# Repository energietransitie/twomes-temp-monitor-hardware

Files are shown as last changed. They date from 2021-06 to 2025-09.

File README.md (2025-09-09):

# Twomes Temperature Monitor Hardware

This repository contains the open hardware design files for the battery powered Twomes Temperature Monitor hardware, which can read measurement data from a varity of sensors:
* two [DS18b20(Z)](https://www.maximintegrated.com/en/products/sensors/DS18B20.html) temperature sensors in clamps that can be connected the supply water pipe (from the boiler to the hydronic radiators) and return water pipe (from the hydronic radiators to the boiler);
* an [Si7051](https://www.silabs.com/sensors/temperature/si705x/device.si7051) sensor mounted 
on the main PCB itself to measure room temperature;
* a [Twomes CO₂ Monitor Shield](https://github.com/energietransitie/twomes-co2-monitor-hardware) with the [WeMos D1 Mini shield](https://www.wemos.cc/en/latest/d1_mini_shield/index.html) form factor that measures temperature via an [Si7051](https://www.silabs.com/sensors/temperature/si705x/device.si7051) sensor and a Sensirion [SCD41](https://www.sensirion.com/en/environmental-sensors/carbon-dioxide-sensors/carbon-dioxide-sensor-scd4x/) sensor that measures CO₂ concentration, relative humidity and temperatue;
* a [SEK-SCD41](https://www.sensirion.com/en/environmental-sensors/evaluation-kit-sek-environmental-sensing/evaluation-kit-sek-scd41/) evaluation board that that measures CO₂ concentration, relative humidity and temperature.

The Twomes Temperature Monitor hardware can wirelessly send data to the [Twomes P1 Gateway measurement device](https://github.com/energietransitie/twomes-p1-gateway-firmware) using [ESP-NOW](https://www.espressif.com/en/products/software/esp-now/overview).

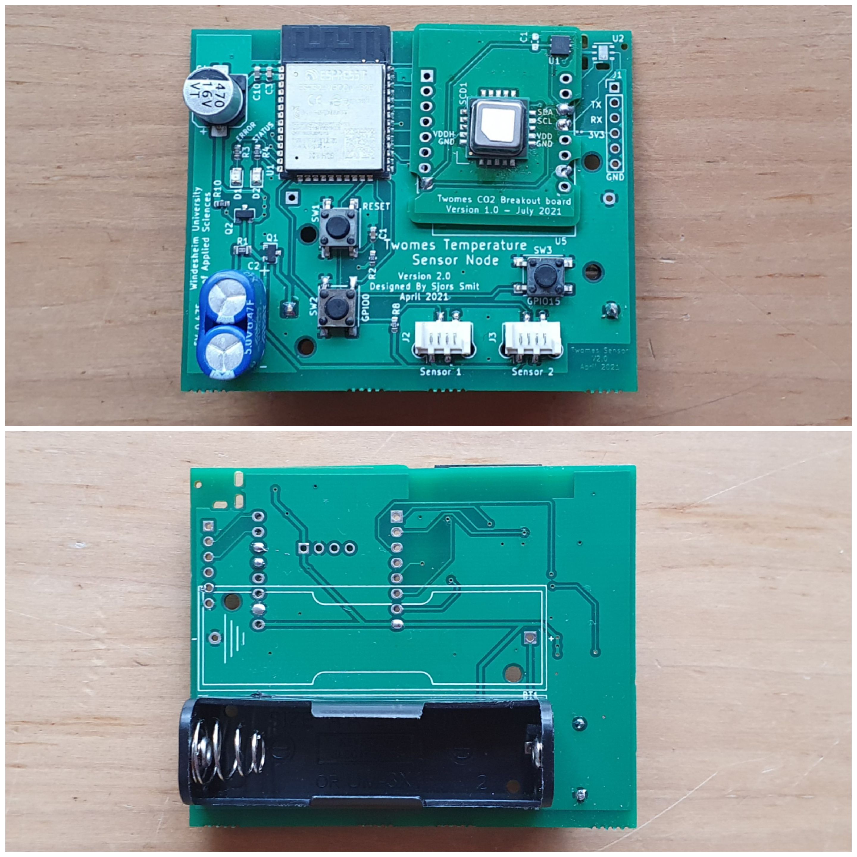
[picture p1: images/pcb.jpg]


## Table of contents
* [General info](#general-info)
* [Producing](#producing)
* [Developing](#developing) 
* [Features](#features)
* [Status](#status)
* [License](#license)
* [Citation](#citation)
* [Credits](#credits)

## General info
This repository contains the the source files and fabrication files of the hardware designs of theTwomes Room Monitor and Twomes Boiler Monitor pcb and its enclosure. It also includes a `docs` folder with recent printouts of the [schematics](./docs/twomes-temp-monitor-hardware-sch.pdf) and [PCB layout](./docs/twomes-temp-monitor-hardware-pcb.pdf). 

For the associated firmwware that you can run on this hardware, please see the following repositories:
* [twomes-twomes-room-monitor-firmware](https://github.com/energietransitie/twomes-room-monitor-firmware);
* [twomes-twomes-boiler-monitor-firmware](https://github.com/energietransitie/twomes-boiler-monitor-firmware);

## Producing
### Printed Circuit Board
To fabricate the printed circuit board you can use various PCB services. 

The folder [pcb/jlcpcb](./pcb/jlcpcb) includes all exported files needed to have the PCBs manufactured by [JLCPCB](https://www.jlcpcb.com). 
Upload the [zipped gerber files](./pcb\jlcpcb\gerber\gerber-TwomesSensor.zip) to the [JLCPCB quote page](https://cart.jlcpcb.com/quote), select the amount of PCBs and a colour for the silkscreen. All other options can be left on default. If SMT assembly is desired, also select this option before ordering. This will take you to a page where the BOM and POS file can be uploaded.  

Assembly of components depends on the variant you need:
* for assembly of a Twomes Boiler Monitor PCB, use the files [BOM-TwomesBoilerSensor.csv](./pcb/jlcpcb/assembly/boiler-monitor/BOM-TwomesBoilerSensor.csv) and [CPL-TwomesBoilerSensor.csv](./pcb/jlcpcb/assembly/boiler-monitor/CPL-TwomesBoilerSensor.csv);
* for assembly of a Twomes Room Monitor PCB, use the files [BOM-TwomesRoomSensor.csv](./pcb/jlcpcb/assembly/room-monitor/BOM-TwomesRoomSensor.csv) and [CPL-TwomesRoomSensor.csv](./pcb/jlcpcb/assembly/room-monitor/CPL-TwomesRoomSensor.csv)

N.B. All components marked "DO NOT PLACE" in the BOM-*.csv files can not be ordered from JLCPCB and need to be ordered from other services and placed manually.

### Enclosure
To fabricate the boiler monitor enclosure or the room room monitor enclosure you can use your own 3D printer or use a 3D printing service. 

Below you find a photo of the boiler enclosure. 
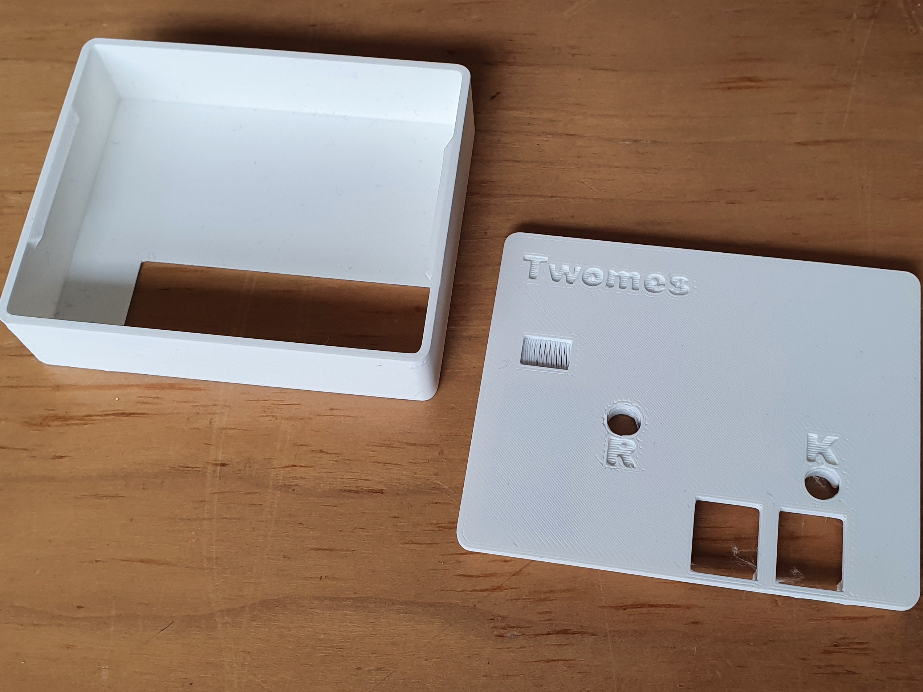
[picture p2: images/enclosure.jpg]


The folder [enclosure/fabrication](./enclosure/fabrication) contains exported STL files. You can print two types of enclusure:
* all enclusures share the same [case](./enclosure/fabrication/twomes-temp-monitor-enclosure-case.stl) and one [button](./enclosure/fabrication/twomes-temp-monitor-enclosure-button.stl)
* for a Twomes Boiler Monitor you need a [boiler monitor lid](./enclosure/fabrication/twomes-boiler-monitor-enclosure-lid.stl) and two [sensor clamps](./enclosure/fabrication/twomes-boiler-monitor-enclosure-clamp.stl); 
* for a Twomes Room Monitor you need a [room monitor lid](./enclosure/fabrication/twomes-room-monitor-enclosure-lid.stl).

The STL files can be imported into any slicer and turned into G-Code for a 3D printer. You can also upload the STL files to an online 3D printing service of your choice.

## Developing

### Printed Circuit Board
To change the hardware design of the PCB, you need:
* [KiCad](https://www.kicad.org/download/) installed to change te PCB design. 

The KiCad source files of the PCB can be found in the folder [pcb](./pcb).

To convert the PCBs into a format suitable for fabrication, consult the webpage of your PCB manufacturer of choice. For example, see the [JLCPCB guide on how to export Gerbers](https://support.jlcpcb.com/article/149-how-to-generate-gerber-and-drill-files-in-kicad) and the  [JLCPCB guide how to export the BOM and POS files](https://support.jlcpcb.com/article/84-how-to-generate-the-bom-and-centroid-file-from-kicad). You may also use a KiCad plug-in for this purpose such as [kicad-jlcpcb-tools](https://github.com/Bouni/kicad-jlcpcb-tools).

### Enclosure
To change the hardware design of the enclosure, you need either:
* [Autodesk Fusion 360](https://www.kicad.org/download/) installed (Autodesk provides 30 day free trials and [free one-year educational access](https://www.autodesk.com/education/edu-software/overview?sorting=featured&filters=individual) to its products and services for eligible students, teachers and research staff); 
* or [FreeCAD](https://www.freecadweb.org/), an open source alternative.

The source files of the enclosure can be found in the folder [enclosure](./enclosure). We include both .f3d source files and .step source files we obtained after conversion.
## Features
The Twomes Temperature Monitor device features the follwoing main hardware components:
* [ESP32-WROOM-32E](https://www.espressif.com/sites/default/files/documentation/esp32-wroom-32e_esp32-wroom-32ue_datasheet_en.pdf) module;
* supercapacitor to assist the battery in high-current bursts.
* battery holder for a 3.6 V AA-size battery, such as the SAFT LS14500 Lithium Thionyl battery.
* FTDI compatible serial programming header (3.3 V).

To-do:
* remove `SW2` (not used in newer firmware)
* remove holes above SW2 and SW3 in enclosure lids (SW3 not used in newer firmware; SW2 does not need to be user accessible, only used during deployment))  
* remove letters 'R' and 'K' from enclusure lids (only a single end-user accessible button used in newer firmware )
## Status
Project is: _in progress_

## License
The hardware designs in this repository are available under the [CERN-OHL-P v2 license](./LICENSE), Copyright 2022 [Research group Energy Transition, Windesheim University of Applied Sciences](https://windesheim.nl/energietransitie)

## Citation

If you use this repository in your research or work, please cite the following pre-print, which describes the overall NeedForHeat DataGear system of which this repository is a part:

> Ter Hofte, H., & van Ravenzwaaij, N. (2025). *NeedForHeat DataGear: An Open Monitoring System to Accelerate the Residential Heating Transition*. arXiv preprint arXiv:2509.06927. https://doi.org/10.48550/arXiv.2509.06927

**Note:** This is a pre-print submitted on 8 Sep 2025 and has not yet been peer-reviewed. For the full paper, see [https://arxiv.org/abs/2509.06927](https://arxiv.org/abs/2509.06927).

## Credits
This open hardware design is made by:
* Sjors Smit · [@Shorts1999](https://github.com/Shorts1999)

Thanks also go to:
* Fredrik-Otto Lautenbag ·  [@Fredrik1997](https://github.com/Fredrik1997)
* Gerwin Buma ·  [@GerwinBuma](https://github.com/GerwinBuma) 
* Marco Winkelman · [@MarcoW71](https://github.com/MarcoW71)

Product owner:
* Marco Winkelman · [@MarcoW71](https://github.com/MarcoW71)

We use and gratefully acknowlegde the efforts of the makers of the following designs:
* [KiCad Libraries](https://kicad.github.io/), by the KiCad Development Team, licensed under [an adapted version of the CC-BY-SA 4.0 License](https://www.kicad.org/libraries/license/)

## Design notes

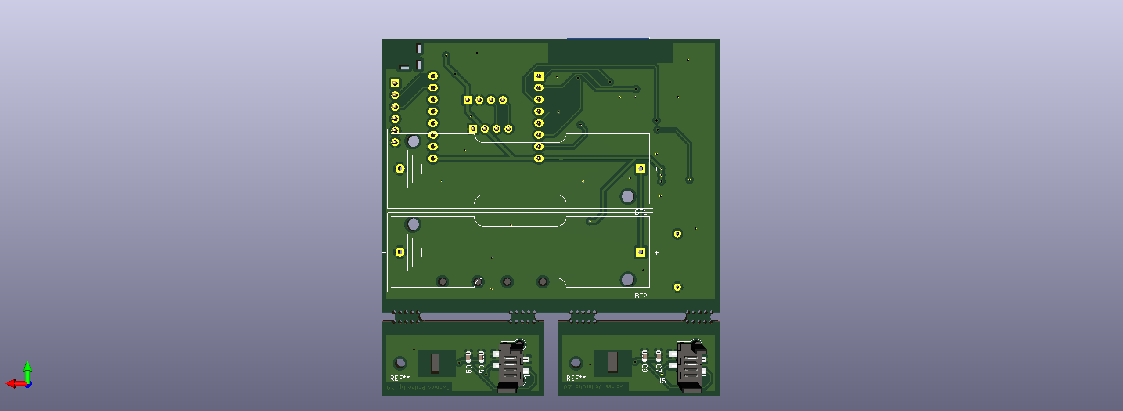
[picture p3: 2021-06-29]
images/twomes-temp-monitor-hardware-bottom.png

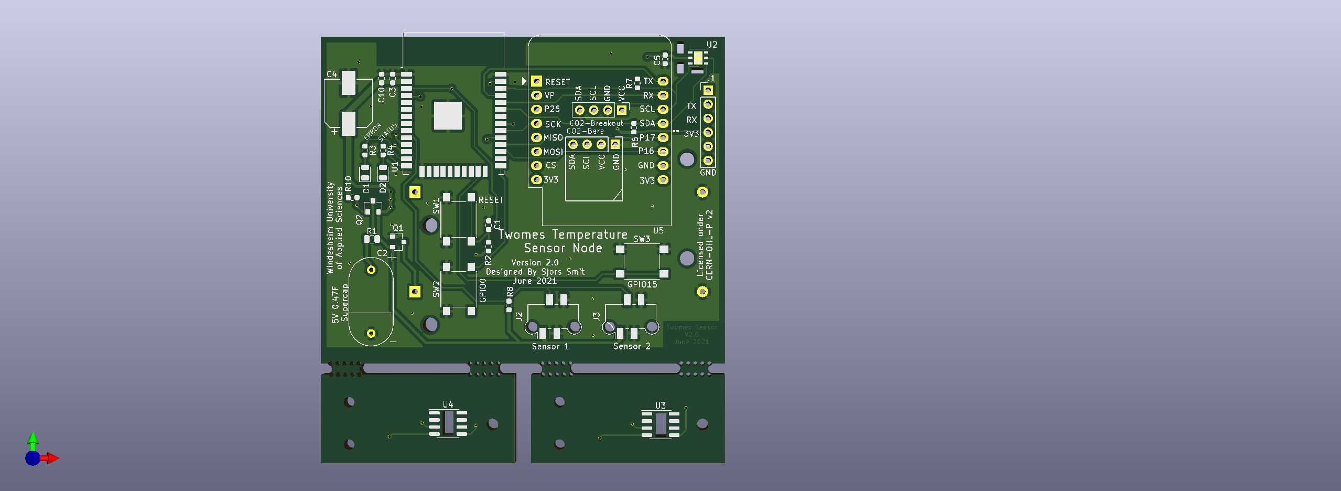
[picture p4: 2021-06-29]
images/twomes-temp-monitor-hardware-top-nomodels.png

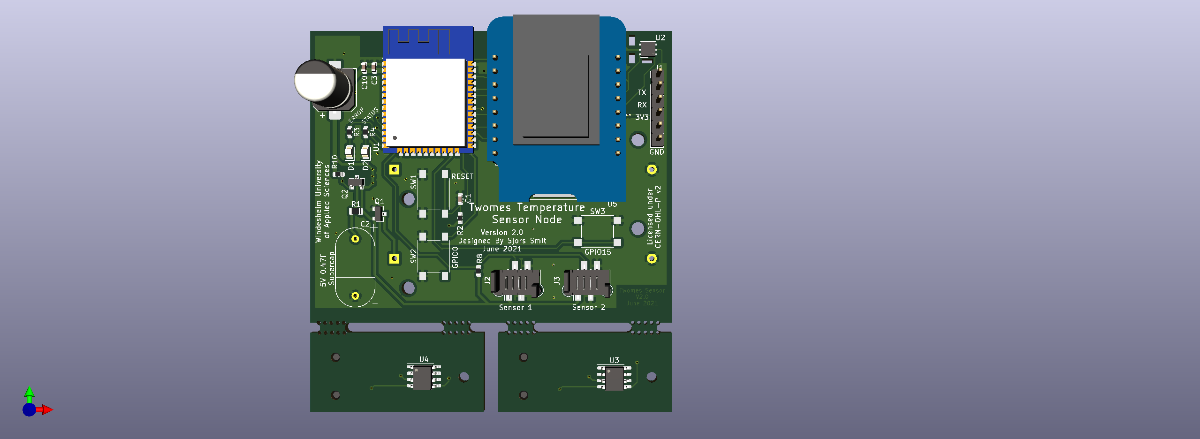
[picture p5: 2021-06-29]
images/twomes-temp-monitor-hardware-top.png

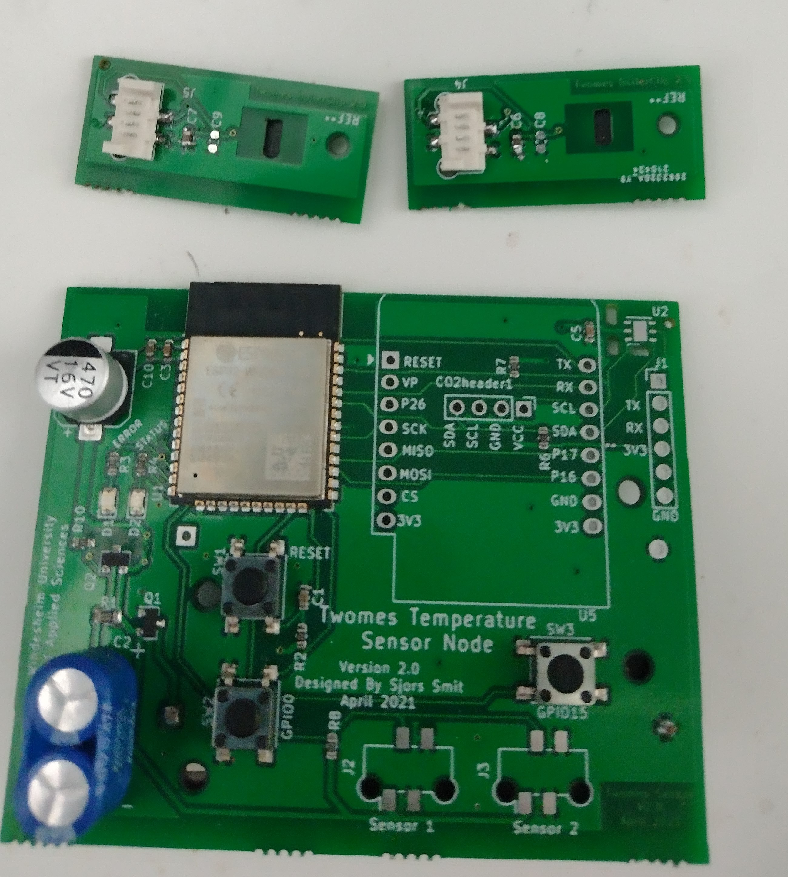
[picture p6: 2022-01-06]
images/Front.jpg

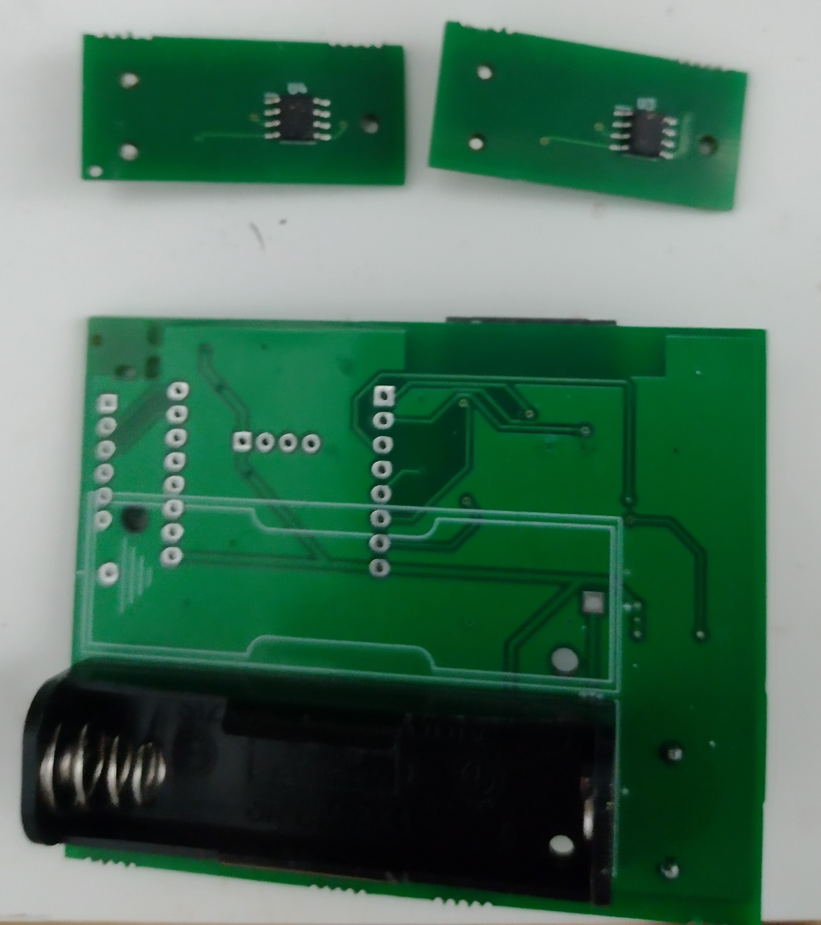
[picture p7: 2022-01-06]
images/Back.jpg

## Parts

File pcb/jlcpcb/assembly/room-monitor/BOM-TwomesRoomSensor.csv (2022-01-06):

Comment | Designator | Footprint | LCSC
LS14500 | BT1,BT2 | Battery:BatteryHolder_Keystone_2460_1xAA | DO NOT PLACE
1uF | C1,C6,C7 | Capacitor_SMD:C_0603_1608Metric | C15849
0.47F | C2 | SuperCap | DO NOT PLACE
470uF | C4 | Capacitor_SMD:CP_Elec_8x10.5 | C141429
100nF | C3,C5,C8,C9 | Capacitor_SMD:C_0603_1608Metric | C14663
10uF | C10 | Capacitor_SMD:C_0603_1608Metric | C19702
RED_LED | D1 | LED_SMD:LED_0805_2012Metric | C84256
GREEN_LED | D2 | LED_SMD:LED_0805_2012Metric | C2297
Female header | J1 | Connector_PinHeader_2.54mm:PinHeader_1x06_P2.54mm_Vertical | DO NOT PLACE
Molex PicoFlex 90814 | J2,J3,J4,J5 | Connector_Molex:Molex_Picoflex_90814-0004_2x02_P1.27mm_Vertical | DO NOT PLACE
SolderJumper | JP1 | Resistor_SMD:R_0201_0603Metric | DO NOT PLACE
PMV48XP,215 | Q1,Q2 | Package_TO_SOT_SMD:SOT-23 | C75560
100R | R1 | Resistor_SMD:R_0805_1608Metric | C17408
10K | R2 | Resistor_SMD:R_0603_1608Metric | C25804
1K | R3,R4 | Resistor_SMD:R_0603_1608Metric | C21190
10k | R6,R7,R10 | Resistor_SMD:R_0603_1608Metric | C25804
4k7 | R8 | Resistor_SMD:R_0603_1608Metric | C23162
SW_Push | SW1,SW2,SW3 | Button_Switch_SMD:SW_Push_1P1T_NO_6x6mm_H9.5mm | C83206
ESP32-WROOM-32E | U1 | RF_Module:ESP32-WROOM-32 | C701343
Si7051-A20 | U2 | Package_DFN_QFN:DFN-6-1EP_3x3mm_P0.95mm_EP1.7x2.6mm | C129804
DS18B20Z | U3,U4 | Package_SO:SOIC-8_3.9x4.9mm_P1.27mm | DO NOT PLACE
WeMos_D1_mini_breakout | U5 | Module:WEMOS_D1_mini_light_shield-Breakout | DO NOT PLACE

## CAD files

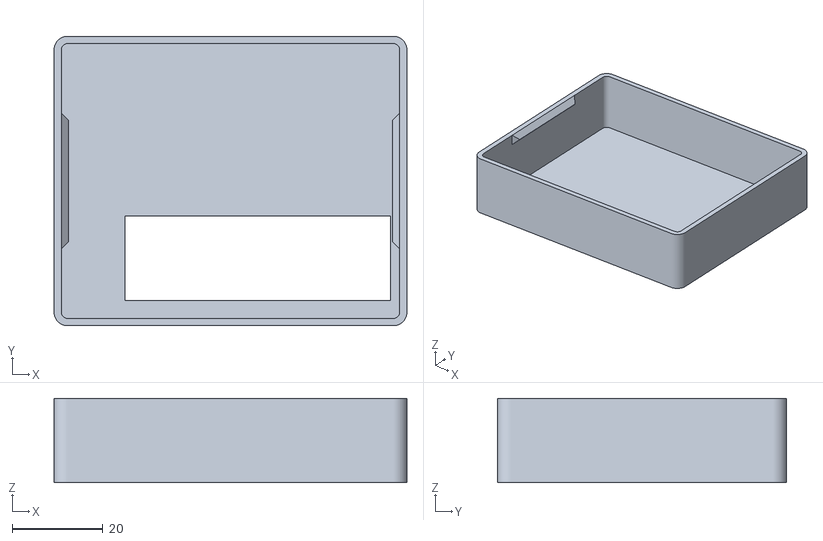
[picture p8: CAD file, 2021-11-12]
enclosure/fabrication/twomes-temp-monitor-enclosure-case.stl
77.7 x 63.7 x 18.5

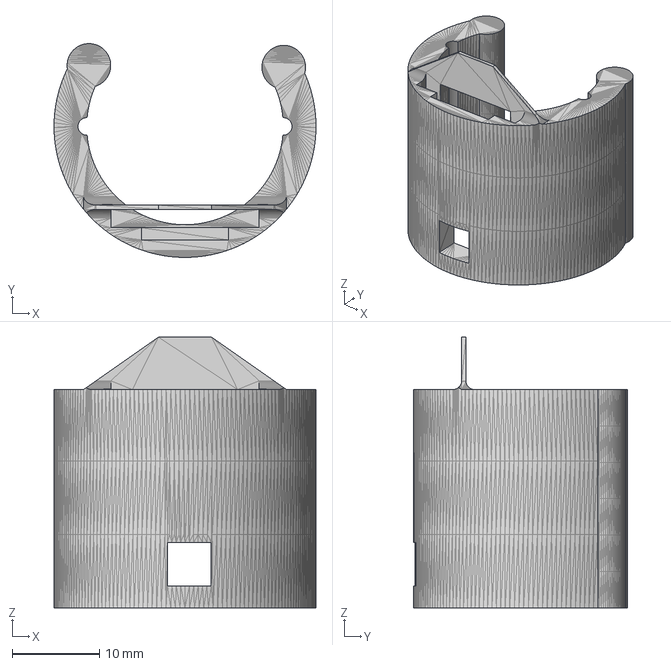
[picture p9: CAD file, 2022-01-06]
enclosure/twomes-boiler-monitor-enclosure-clamp.step
30.0 x 24.5 x 31.0 mm

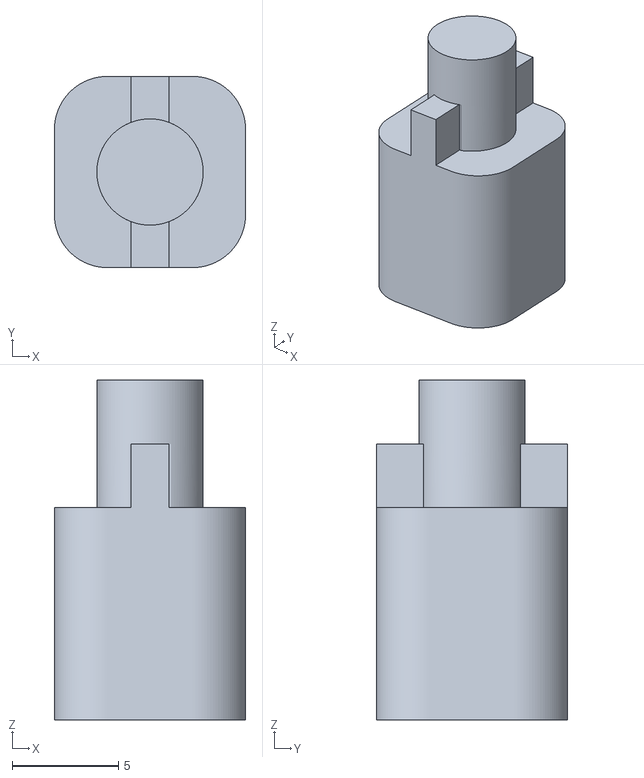
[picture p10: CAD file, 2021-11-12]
enclosure/fabrication/twomes-temp-monitor-enclosure-button.stl
9.00 x 9.00 x 16.0

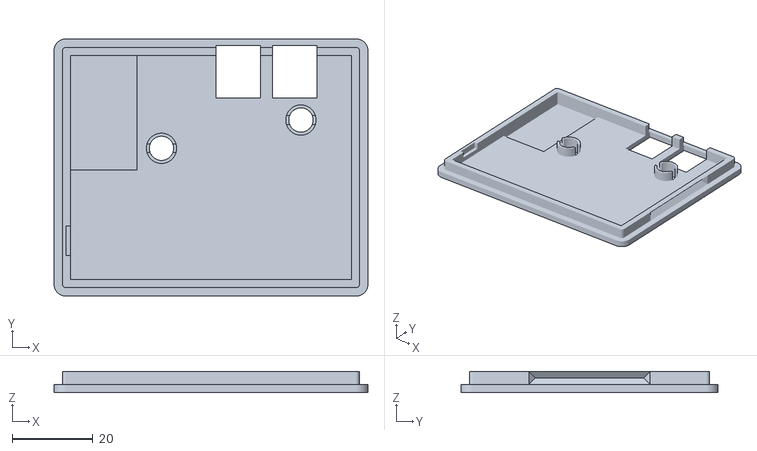
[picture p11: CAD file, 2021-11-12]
enclosure/fabrication/twomes-boiler-monitor-enclosure-lid.stl
77.7 x 63.7 x 5.20

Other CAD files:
enclosure/twomes-temp-monitor-enclosure-case.step
enclosure/twomes-room-monitor-enclosure-lid.step
enclosure/fabrication/twomes-room-monitor-enclosure-lid.stl
enclosure/twomes-temp-monitor-enclosure-button.step
enclosure/fabrication/twomes-boiler-monitor-enclosure-clamp.stl
enclosure/twomes-boiler-monitor-enclosure-clamp.f3d
enclosure/twomes-room-monitor-enclosure.f3d
enclosure/twomes-temp-monitor-enclosure-button.f3d

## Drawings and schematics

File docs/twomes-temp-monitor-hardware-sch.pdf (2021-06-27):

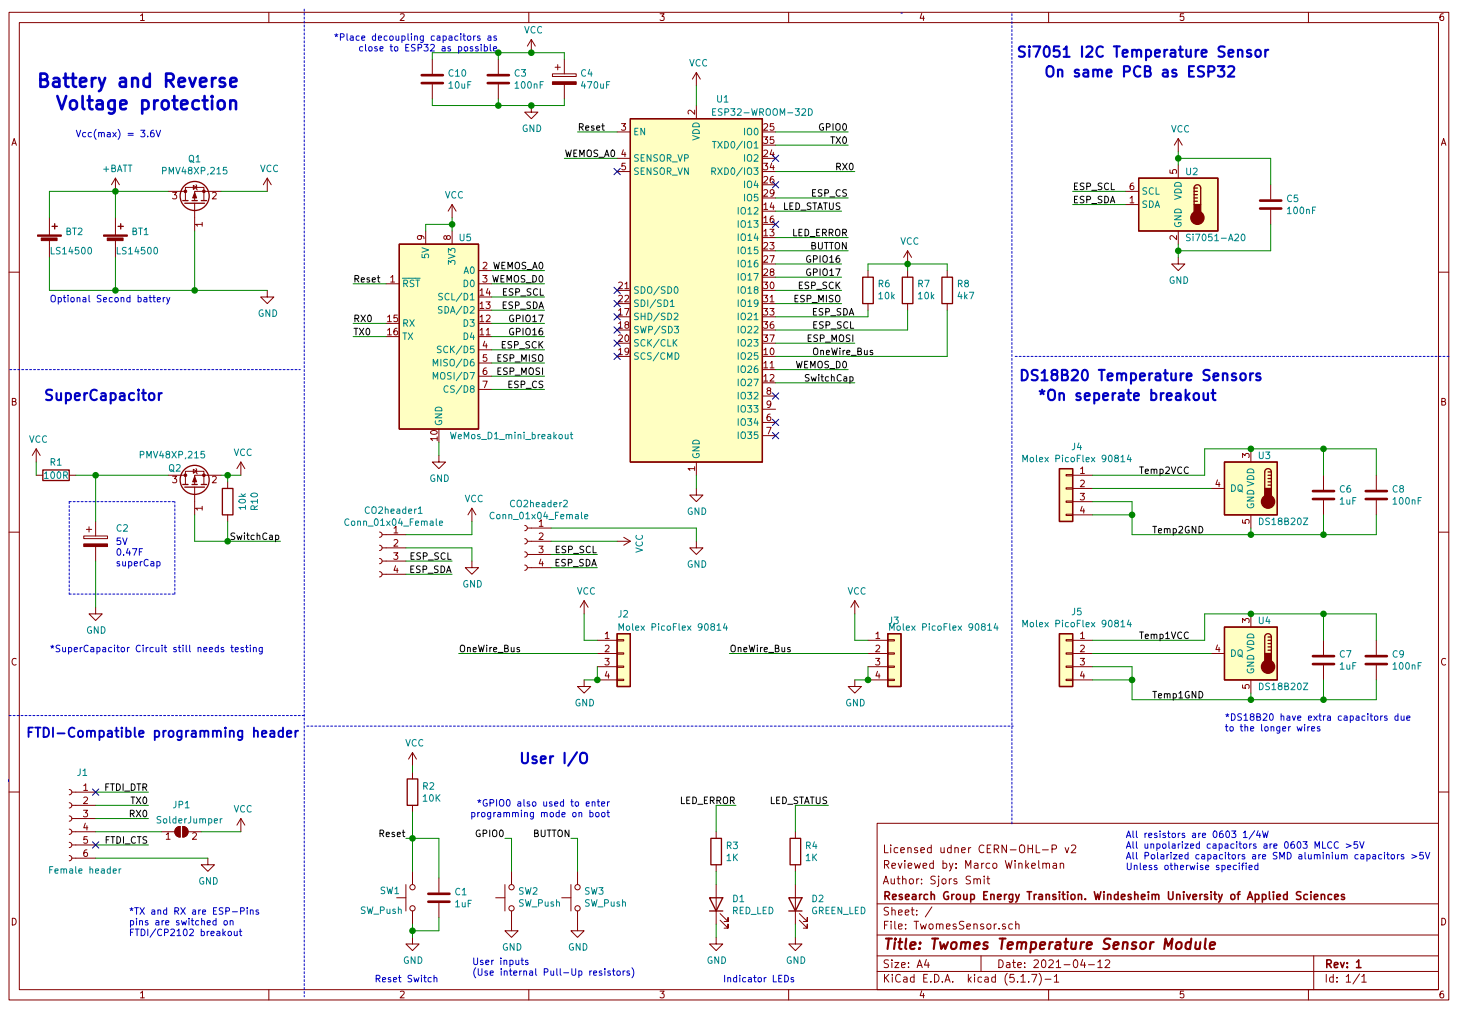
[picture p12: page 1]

*Place decoupling capacitors as
close to ESP32 as possible

Si7051 I2C Temperature Sensor
On same PCB as ESP32

2 SCK/CLK 20 SDO/SD0 21 SDI/SD1 22

*SuperCapacitor Circuit still needs testing

*DS18B20 have extra capacitors due

FTDI-Compatible programming header

to the longer wires All resistors are 0603 1/4W

*GPIO0 also used to enter programming mode on boot

Licensed udner CERN-OHL-P v2
Reviewed by: Marco Winkelman
Author: Sjors Smit
File: TwomesSensor.sch Sheet: / Research Group Energy Transition. Windesheim University of Applied Sciences

All unpolarized capacitors are 0603 MLCC >5V
All Polarized capacitors are SMD aluminium capacitors >5V
Unless otherwise specified

*TX and RX are ESP-Pins pins are switched on FTDI/CP2102 breakout

Id: 1/1 Title: Twomes Temperature Sensor Module

User inputs
(Use internal Pull-Up resistors)

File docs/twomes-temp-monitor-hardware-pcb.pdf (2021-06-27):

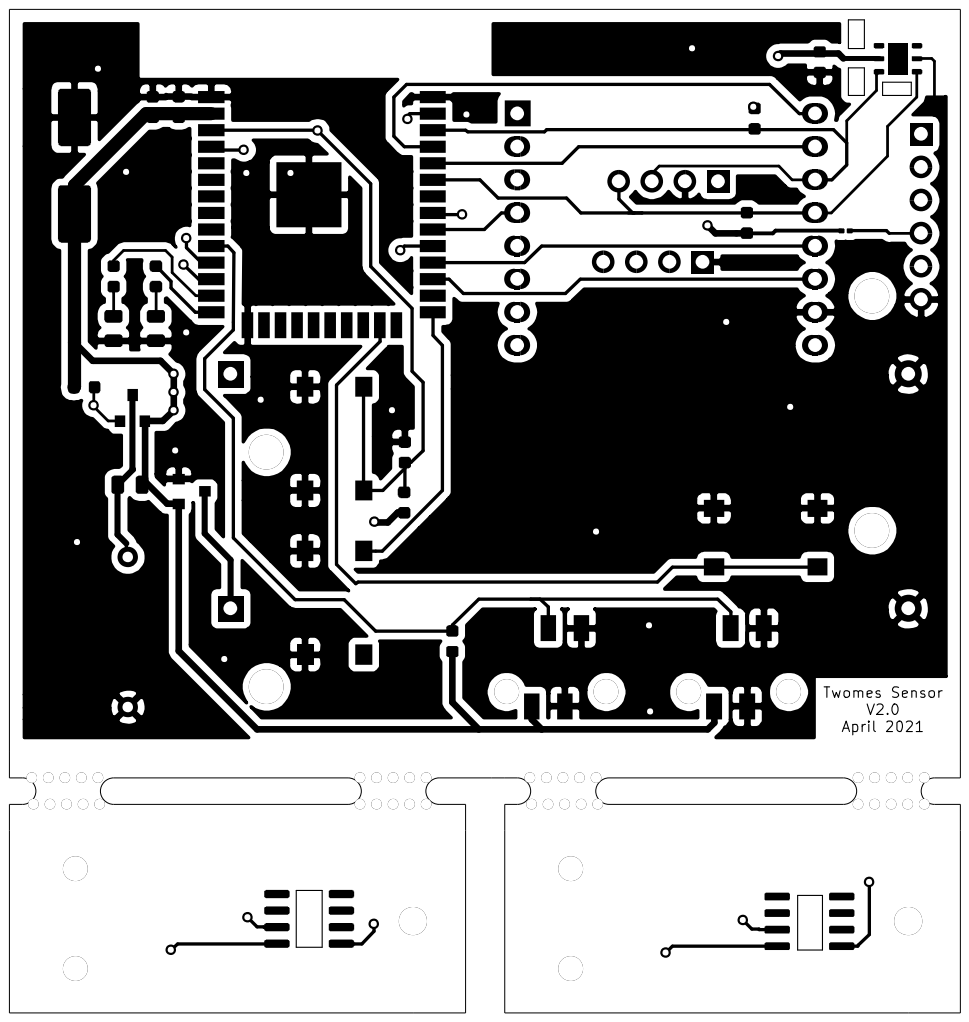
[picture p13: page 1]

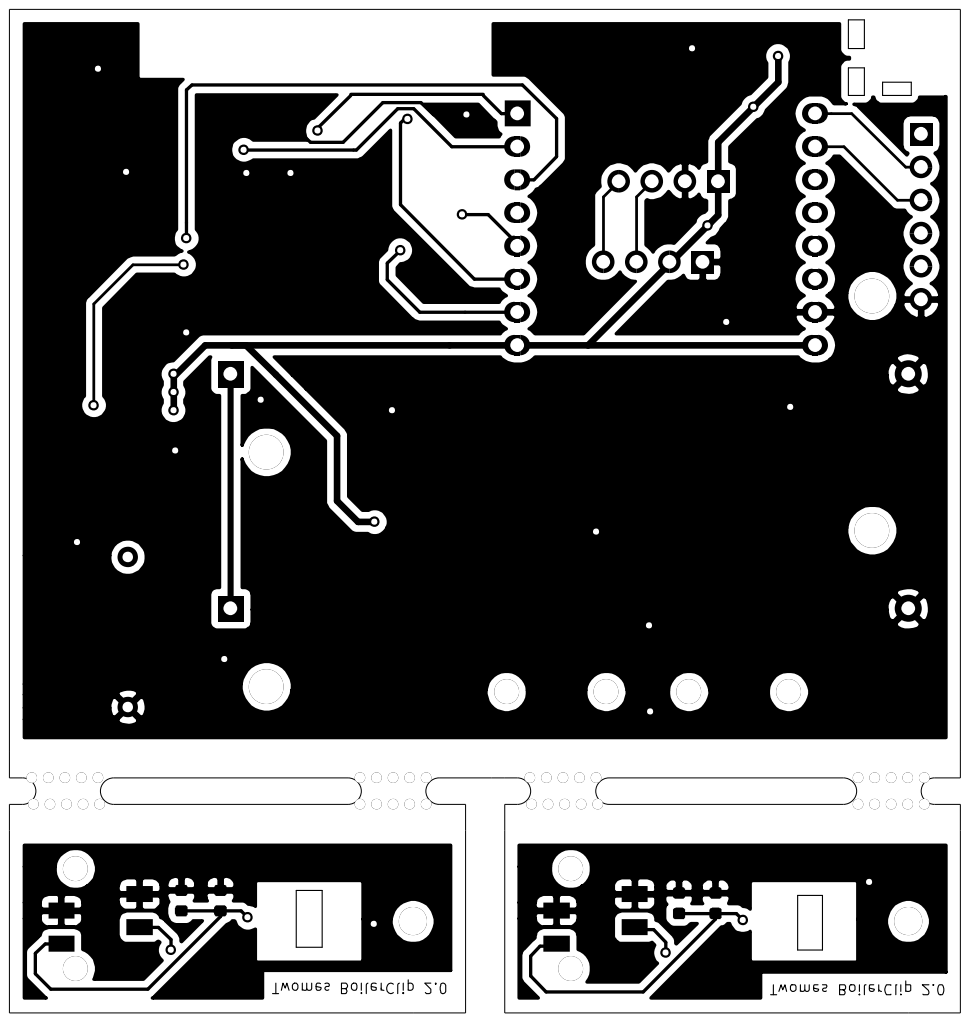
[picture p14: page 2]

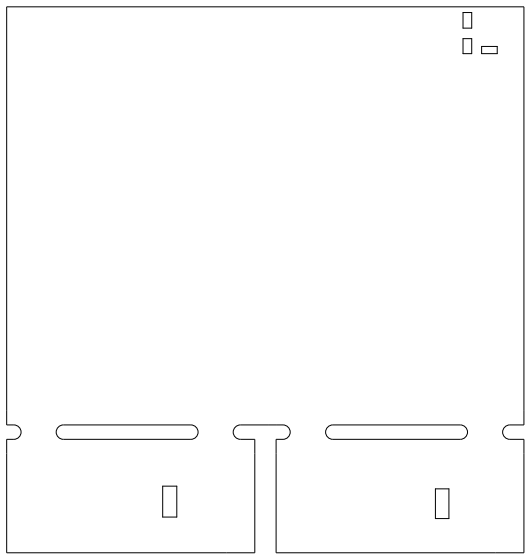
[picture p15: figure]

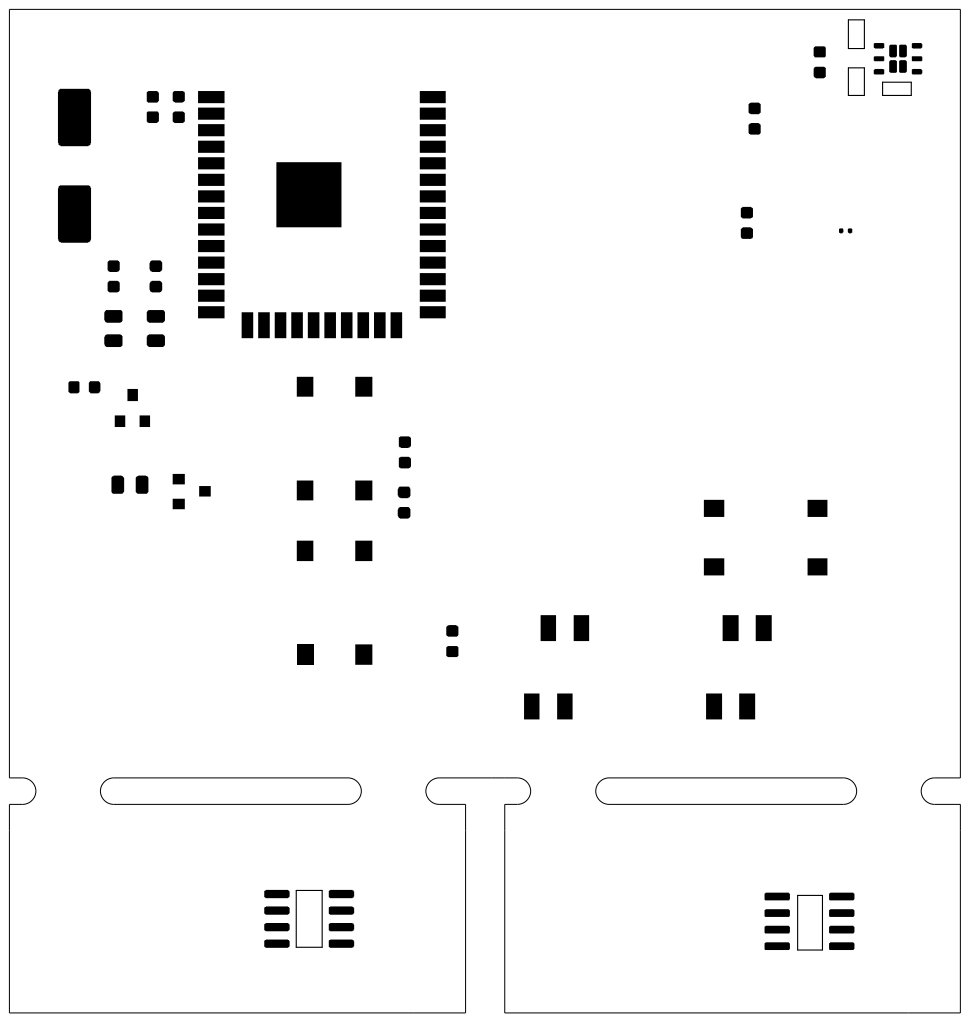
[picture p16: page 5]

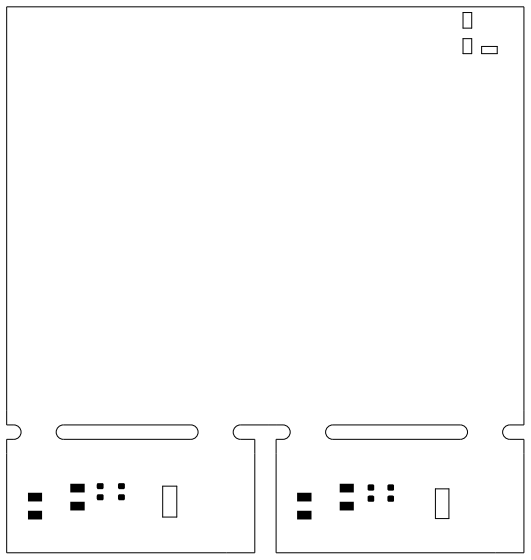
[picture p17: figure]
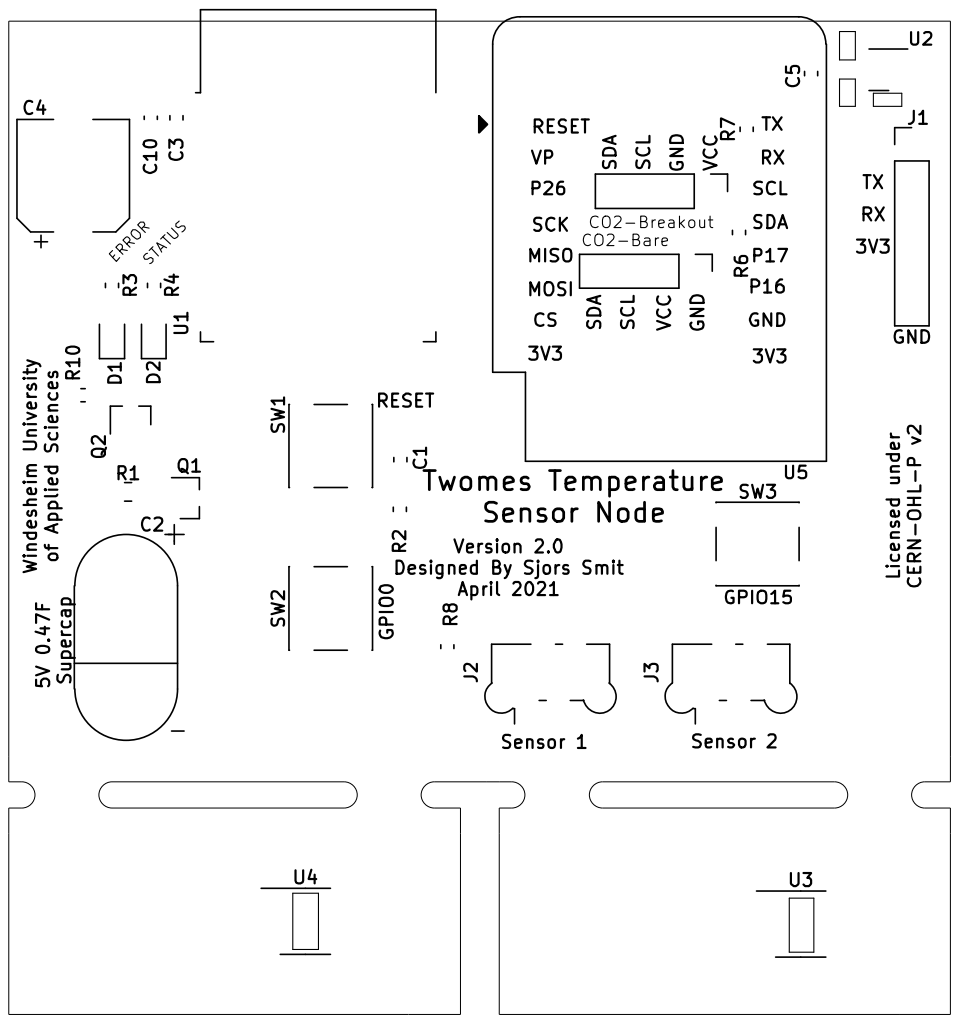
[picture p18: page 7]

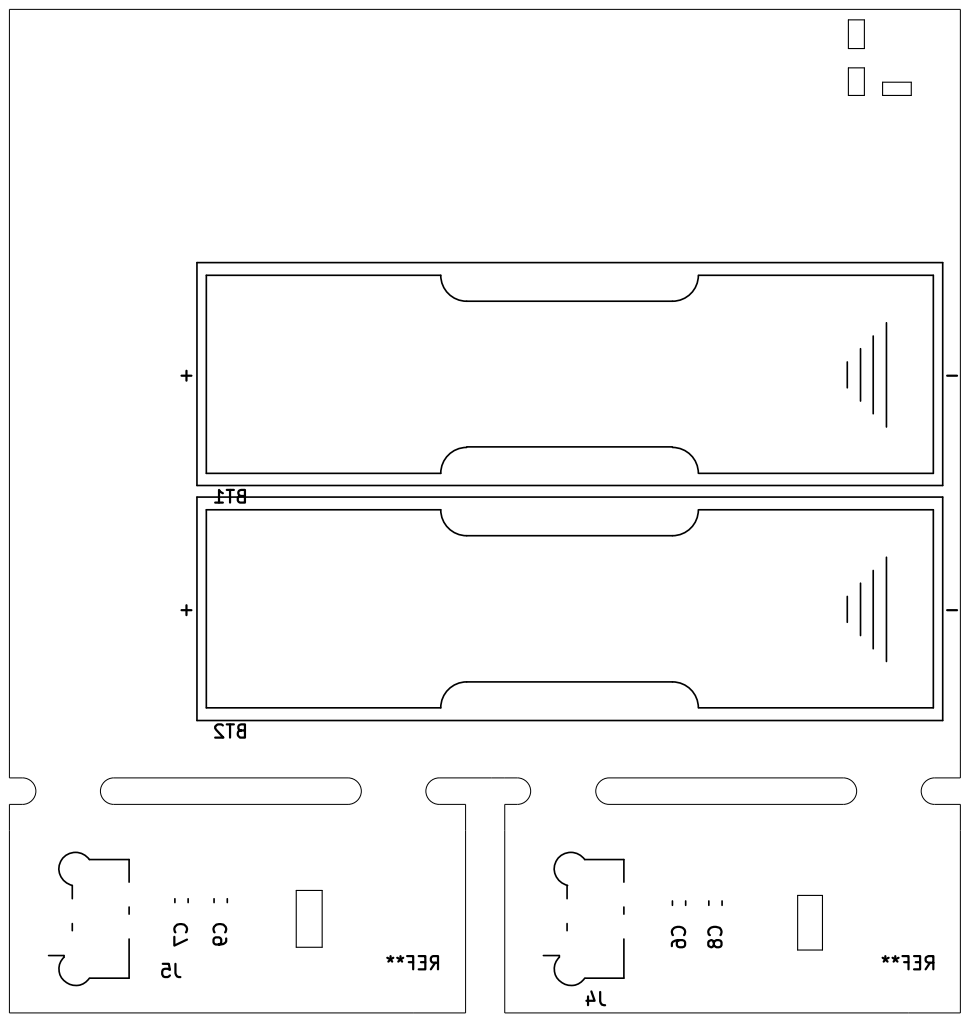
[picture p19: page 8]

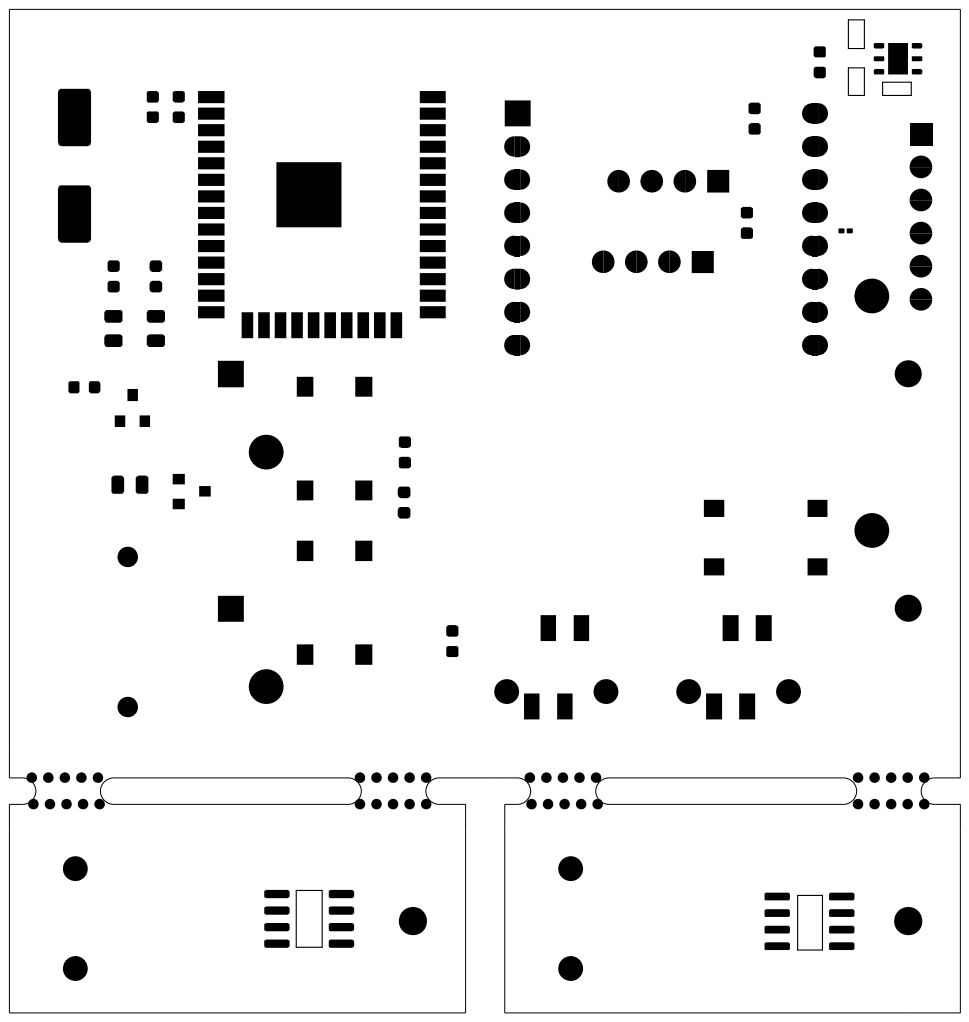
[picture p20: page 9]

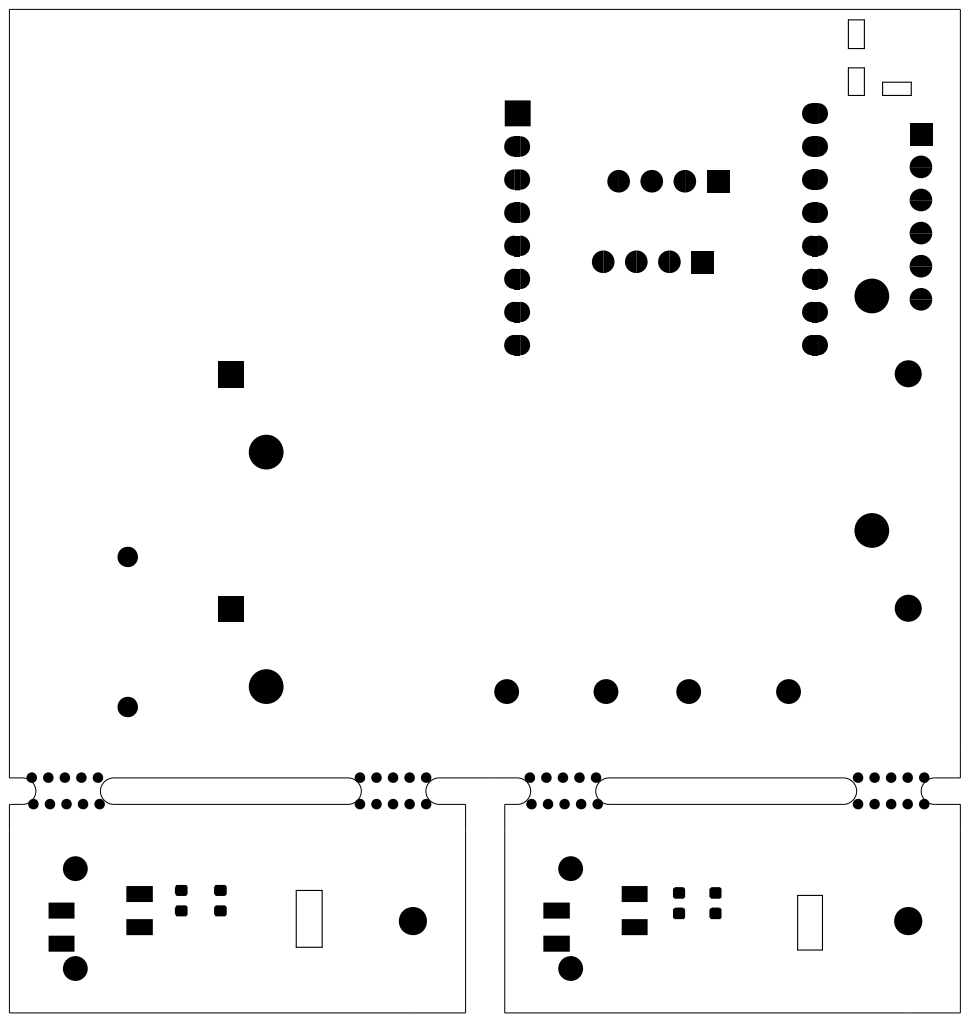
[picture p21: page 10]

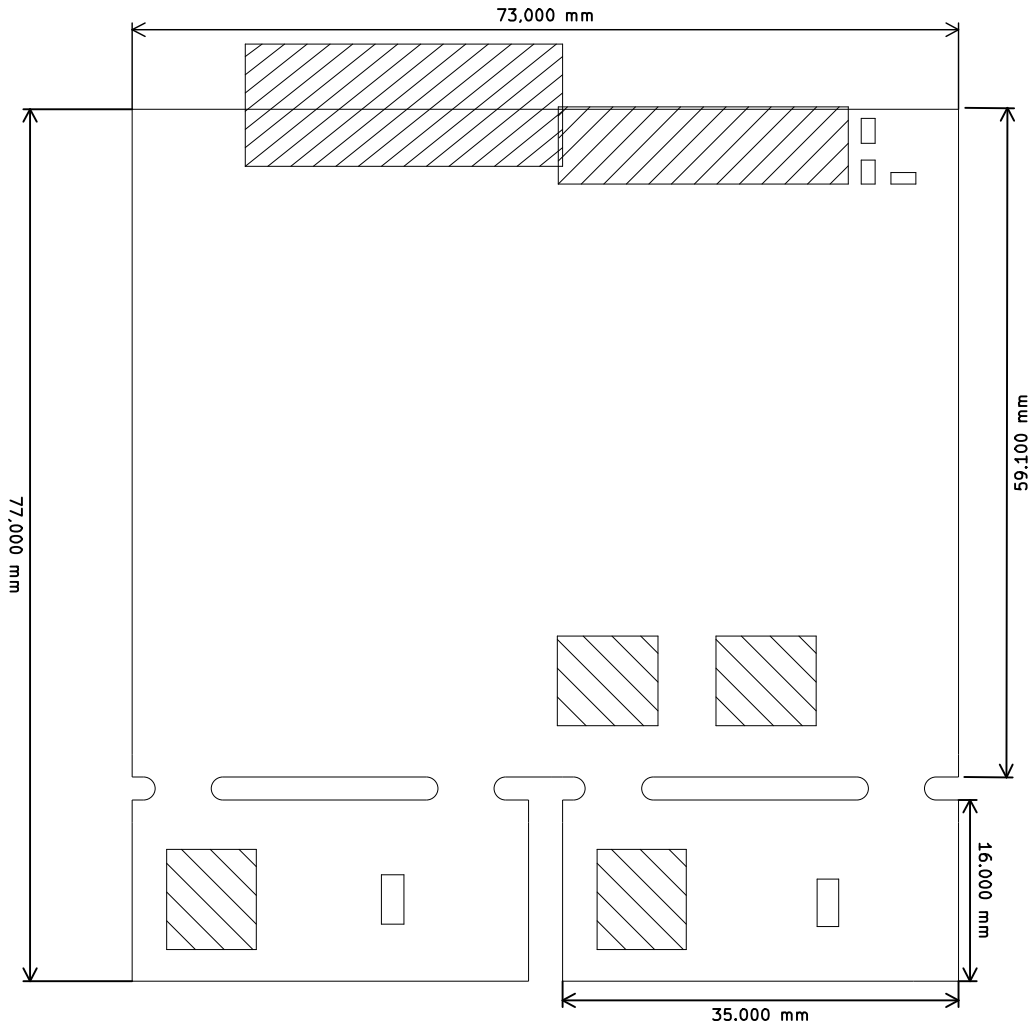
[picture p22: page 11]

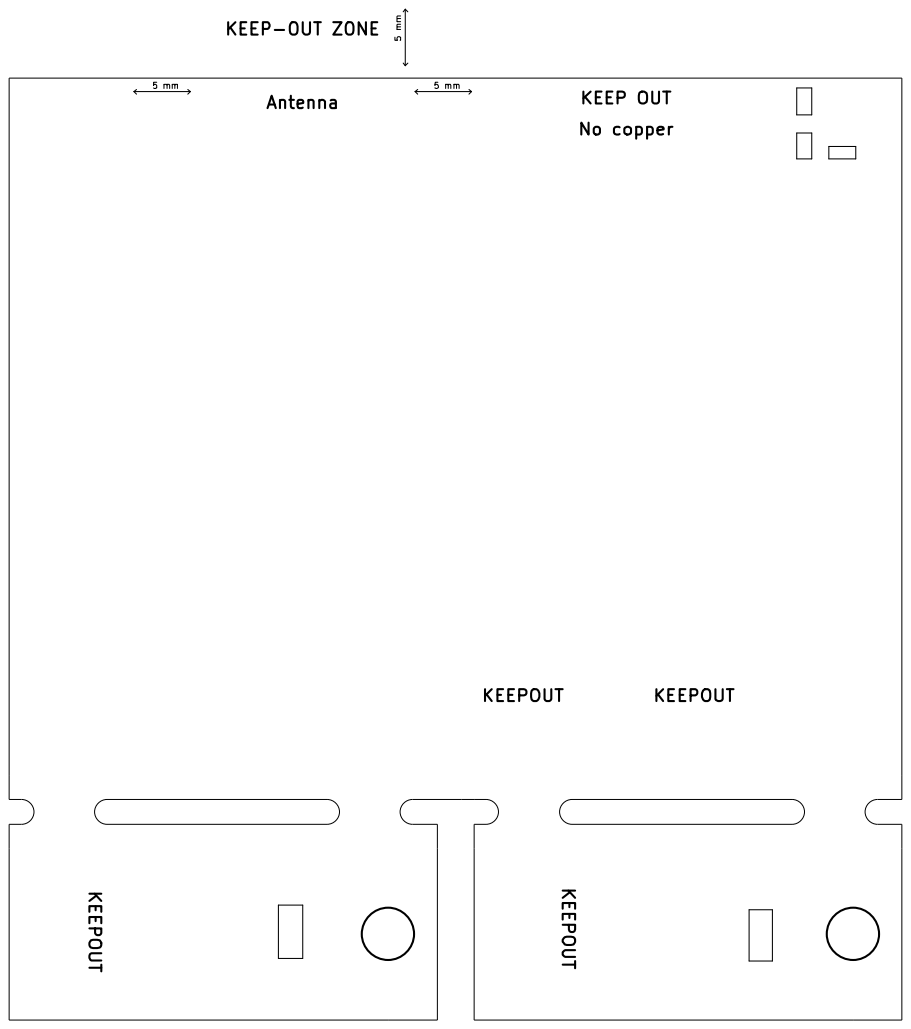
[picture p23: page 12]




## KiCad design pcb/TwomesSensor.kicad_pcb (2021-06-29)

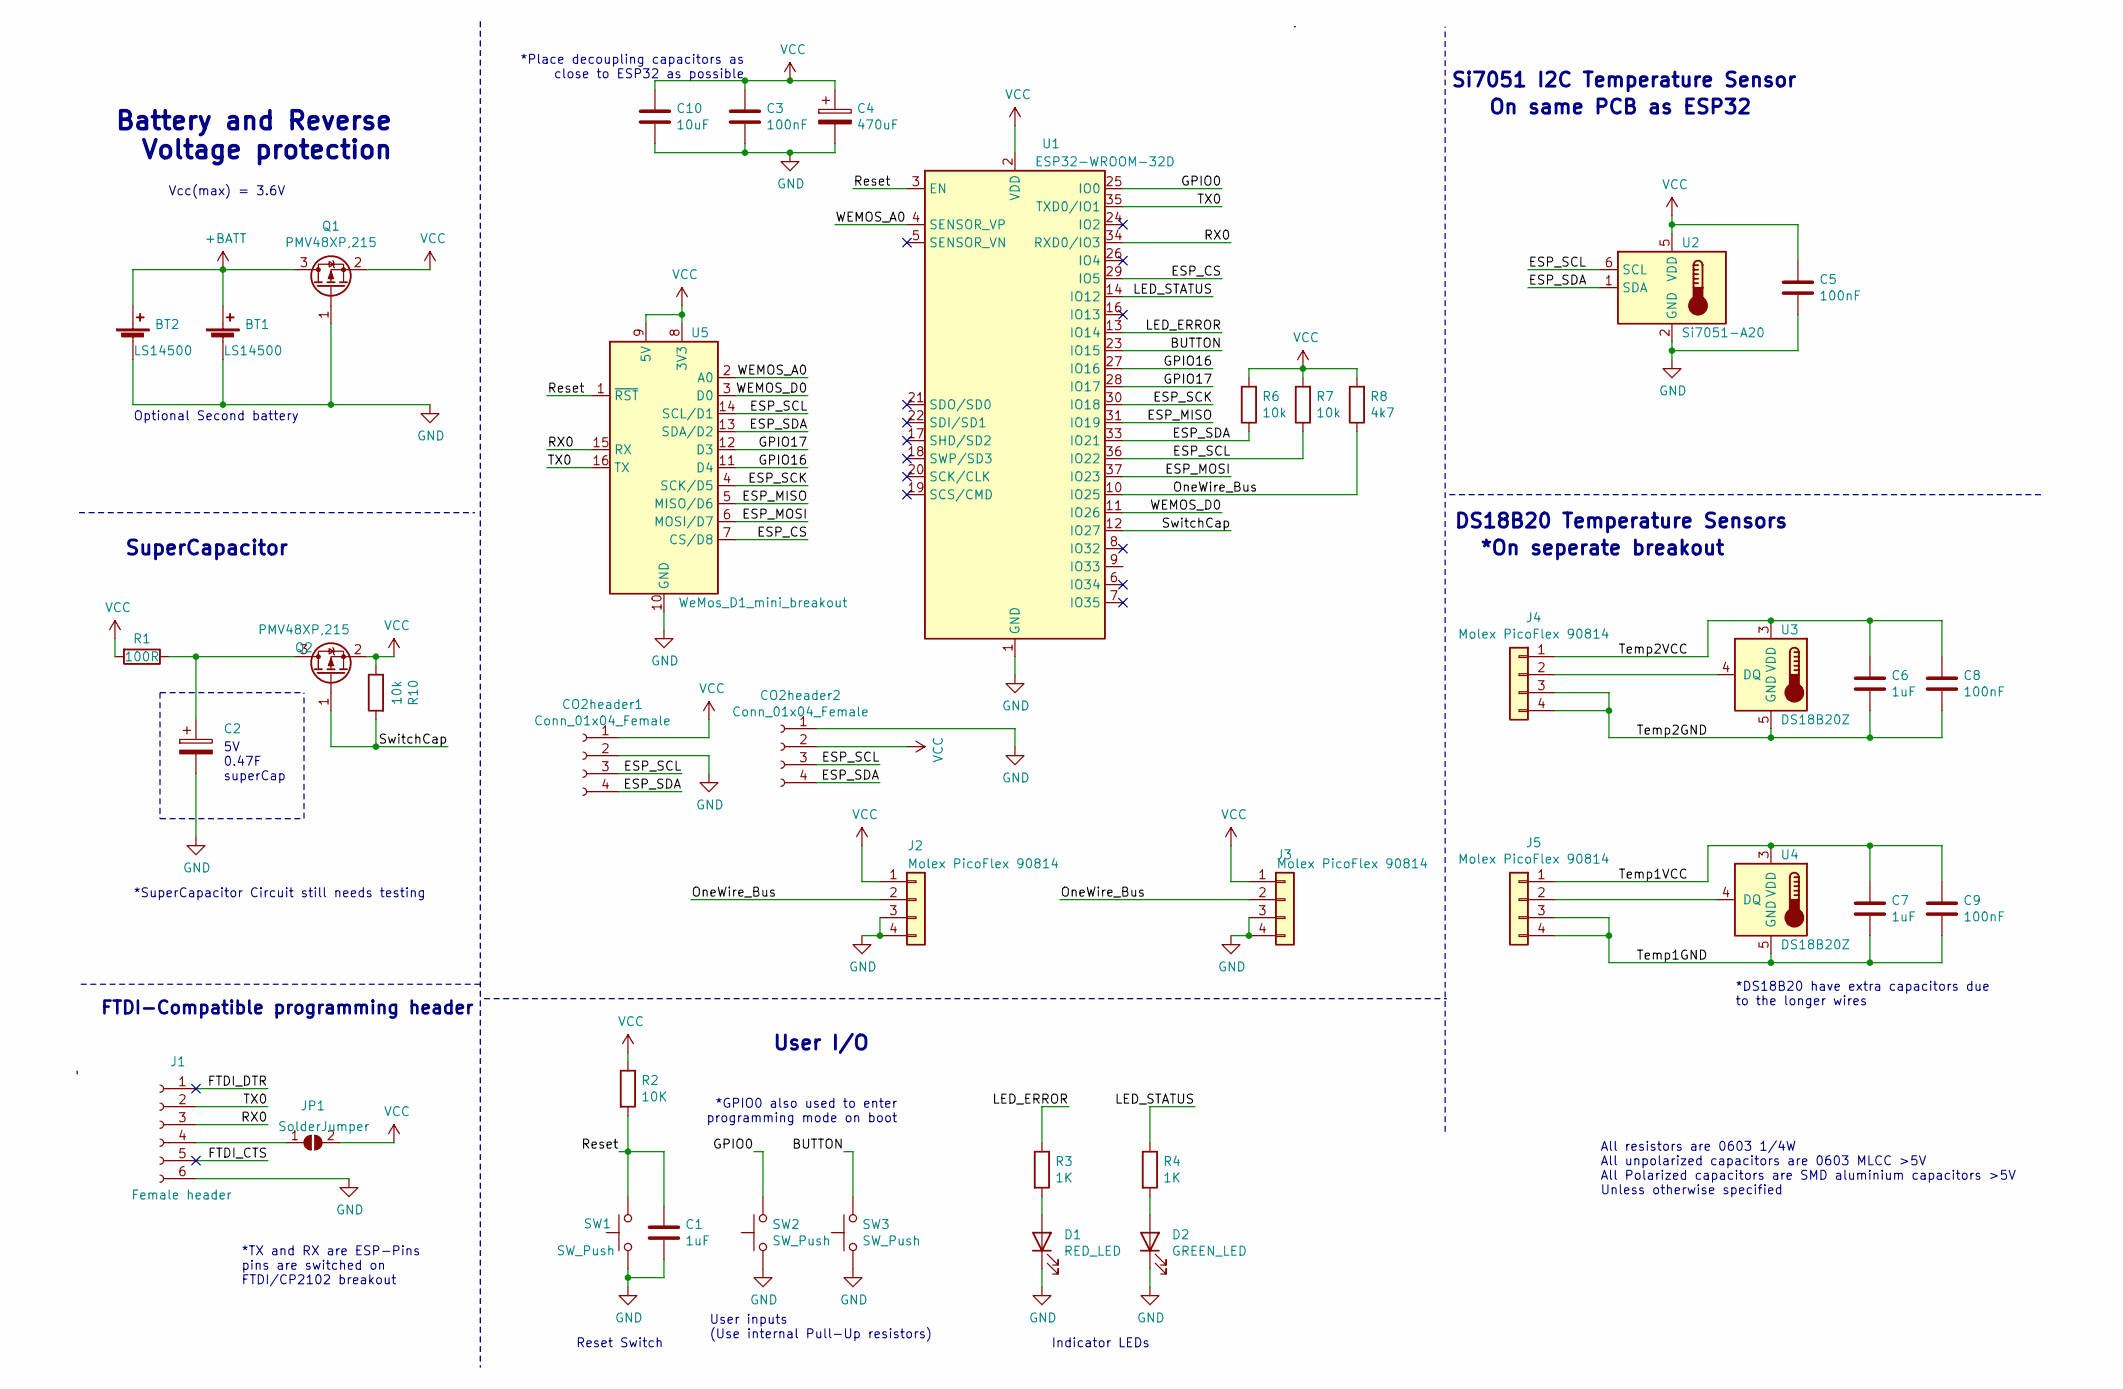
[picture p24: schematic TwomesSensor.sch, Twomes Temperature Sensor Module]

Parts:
BT1, BT2: LS14500; BatteryHolder_Keystone_2460_1xAA
C1, C6, C7: 1uF; C_0603_1608Metric
C2: 0.47F; Supercap-Dual-5V-8x16
C3, C5, C8, C9: 100nF; C_0603_1608Metric
C4: 470uF; CP_Elec_8x10.5
C10: 10uF; C_0603_1608Metric
CO2header1, CO2header2: Conn_01x04_Female; PinHeader_1x04_P2.54mm_Vertical
D1: RED_LED; LED_0805_2012Metric
D2: GREEN_LED; LED_0805_2012Metric
J1: Female header; PinHeader_1x06_P2.54mm_Vertical
J2, J3, J4, J5: Molex PicoFlex 90814; Molex_Picoflex_90814-0004_2x02_P1.27mm_Vertical
JP1: SolderJumper; R_0201_0603Metric
Q1, Q2: PMV48XP,215; SOT-23
R1: 100R; R_0603_1608Metric
R2: 10K; R_0603_1608Metric
R3, R4: 1K; R_0603_1608Metric
R6, R7, R10: 10k; R_0603_1608Metric
R8: 4k7; R_0603_1608Metric
SW1, SW2, SW3: SW_Push; SW_Push_1P1T_NO_6x6mm_H9.5mm
U1: ESP32-WROOM-32D; ESP32-WROOM-32
U2: Si7051-A20; DFN-6-1EP_3x3mm_P0.95mm_EP1.7x2.6mm
U3, U4: DS18B20Z; SOIC-8_3.9x4.9mm_P1.27mm
U5: WeMos_D1_mini_breakout; WEMOS_D1_mini_light

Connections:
+BATT: BT1.1 (+), BT2.1 (+), Q1.3 (D)
/BUTTON: SW3.2, U1.23 (IO15)
/ESP_CS: U1.29 (IO5), U5.7 (CS/D8)
/ESP_MISO: U1.31 (IO19), U5.5 (MISO/D6)
/ESP_MOSI: U1.37 (IO23), U5.6 (MOSI/D7)
/ESP_SCK: U1.30 (IO18), U5.4 (SCK/D5)
/ESP_SCL: CO2header1.3, CO2header2.3, R7.1, U1.36 (IO22), U2.6 (SCL), U5.14 (SCL/D1); also elsewhere on the board
/ESP_SDA: CO2header1.4, CO2header2.4, R6.1, U1.33 (IO21), U2.1 (SDA), U5.13 (SDA/D2); also elsewhere on the board
/FTDI_CTS: J1.5
/FTDI_DTR: J1.1
/GPIO0: SW2.2, U1.25 (IO0)
/GPIO16: U1.27 (IO16), U5.11 (D4)
/GPIO17: U1.28 (IO17), U5.12 (D3)
/LED_ERROR: R3.1, U1.13 (IO14)
/LED_STATUS: R4.1, U1.14 (IO12)
/OneWire_Bus: J2.2, J3.2, R8.1, U1.10 (IO25)
/RX0: J1.3, U1.34 (RXD0/IO3), U5.15 (RX)
/Reset: C1.1, R2.2, SW1.2, U1.3 (EN), U5.1 (~RST)
/SwitchCap: Q2.1 (G), R10.2, U1.12 (IO27)
/TX0: J1.2, U1.35 (TXD0/IO1), U5.16 (TX)
/Temp1GND: C7.2, C9.2, J5.3, J5.4, U4.5 (GND)
/Temp1VCC: C7.1, C9.1, J5.1, U4.3 (VDD)
/Temp2GND: C6.2, C8.2, J4.3, J4.4, U3.5 (GND)
/Temp2VCC: C6.1, C8.1, J4.1, U3.3 (VDD)
/WEMOS_A0: U1.4 (SENSOR_VP), U5.2 (A0)
/WEMOS_D0: U1.11 (IO26), U5.3 (D0)
GND: BT1.2 (-), BT2.2 (-), C1.2, C2.2, C3.2, C4.2, C5.2, C10.2, CO2header1.2, CO2header2.1, D1.1 (K), D2.1 (K), J1.6, J2.3, J2.4, J3.3, J3.4, Q1.1 (G), SW1.1, SW2.1, SW3.1, U1.1 (GND), U1.15 (GND), U1.38 (GND), U1.39 (GND), U2.2 (GND), U5.10 (GND); also elsewhere on the board
unnamed: C2.1, Q2.3 (D), R1.1
unnamed: D1.2 (A), R3.2
unnamed: D2.2 (A), R4.2
unnamed: J1.4, JP1.1 (A)
unnamed: J4.2, U3.4 (DQ)
unnamed: J5.2, U4.4 (DQ)
VCC: C3.1, C4.1, C5.1, C10.1, CO2header1.1, CO2header2.2, J2.1, J3.1, JP1.2 (B), Q1.2 (S), Q2.2 (S), R1.2, R2.1, R6.2, R7.2, R8.2, R10.1, U1.2 (VDD), U2.5 (VDD), U5.8 (3V3), U5.9 (5V); also elsewhere on the board

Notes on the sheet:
FTDI-Compatible programming header
Battery and Reverse Voltage protection
Vcc(max) = 3.6V
User inputs (Use internal Pull-Up resistors)
Reset Switch
On same PCB as ESP32
Si7051 I2C Temperature Sensor
DS18B20 Temperature Sensors
*On seperate breakout
Indicator LEDs
User I/O
SuperCapacitor
5V 0.47F superCap
*SuperCapacitor Circuit still needs testing
*DS18B20 have extra capacitors due to the longer wires
All resistors are 0603 1/4W All unpolarized capacitors are 0603 MLCC >5V All Polarized capacitors are SMD aluminium capacitors >5V Unless otherwise specified
*TX and RX are ESP-Pins pins are switched on FTDI/CP2102 breakout
*GPIO0 also used to enter programming mode on boot
*Place decoupling capacitors as close to ESP32 as possible
Optional Second battery

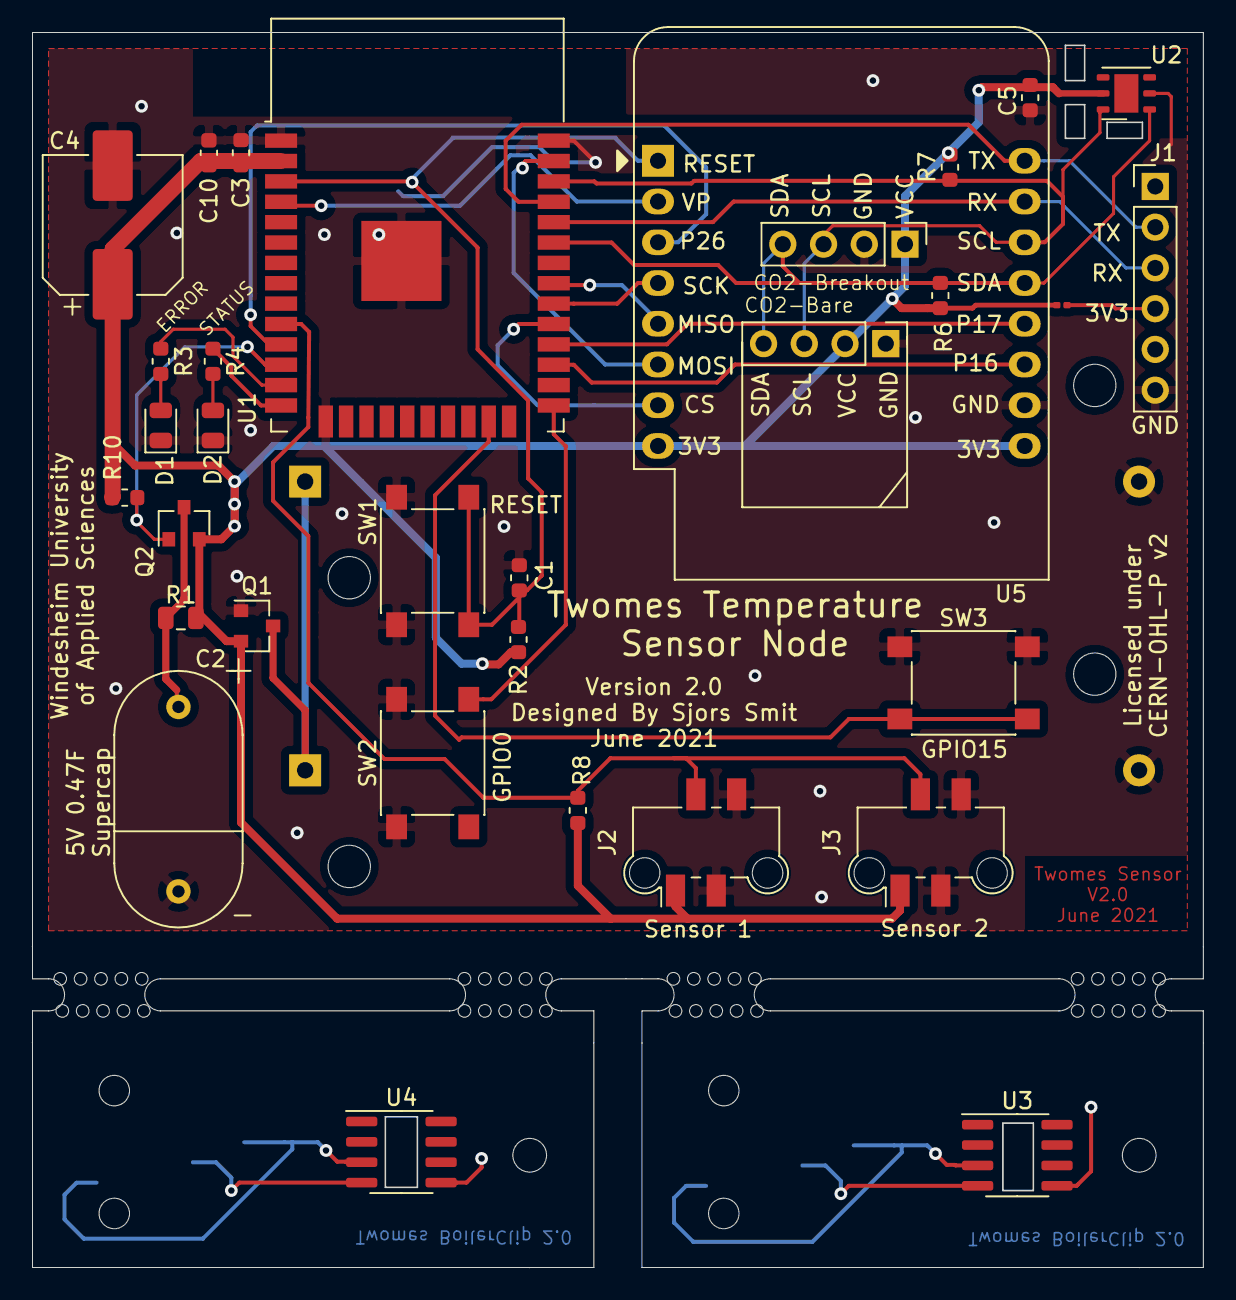
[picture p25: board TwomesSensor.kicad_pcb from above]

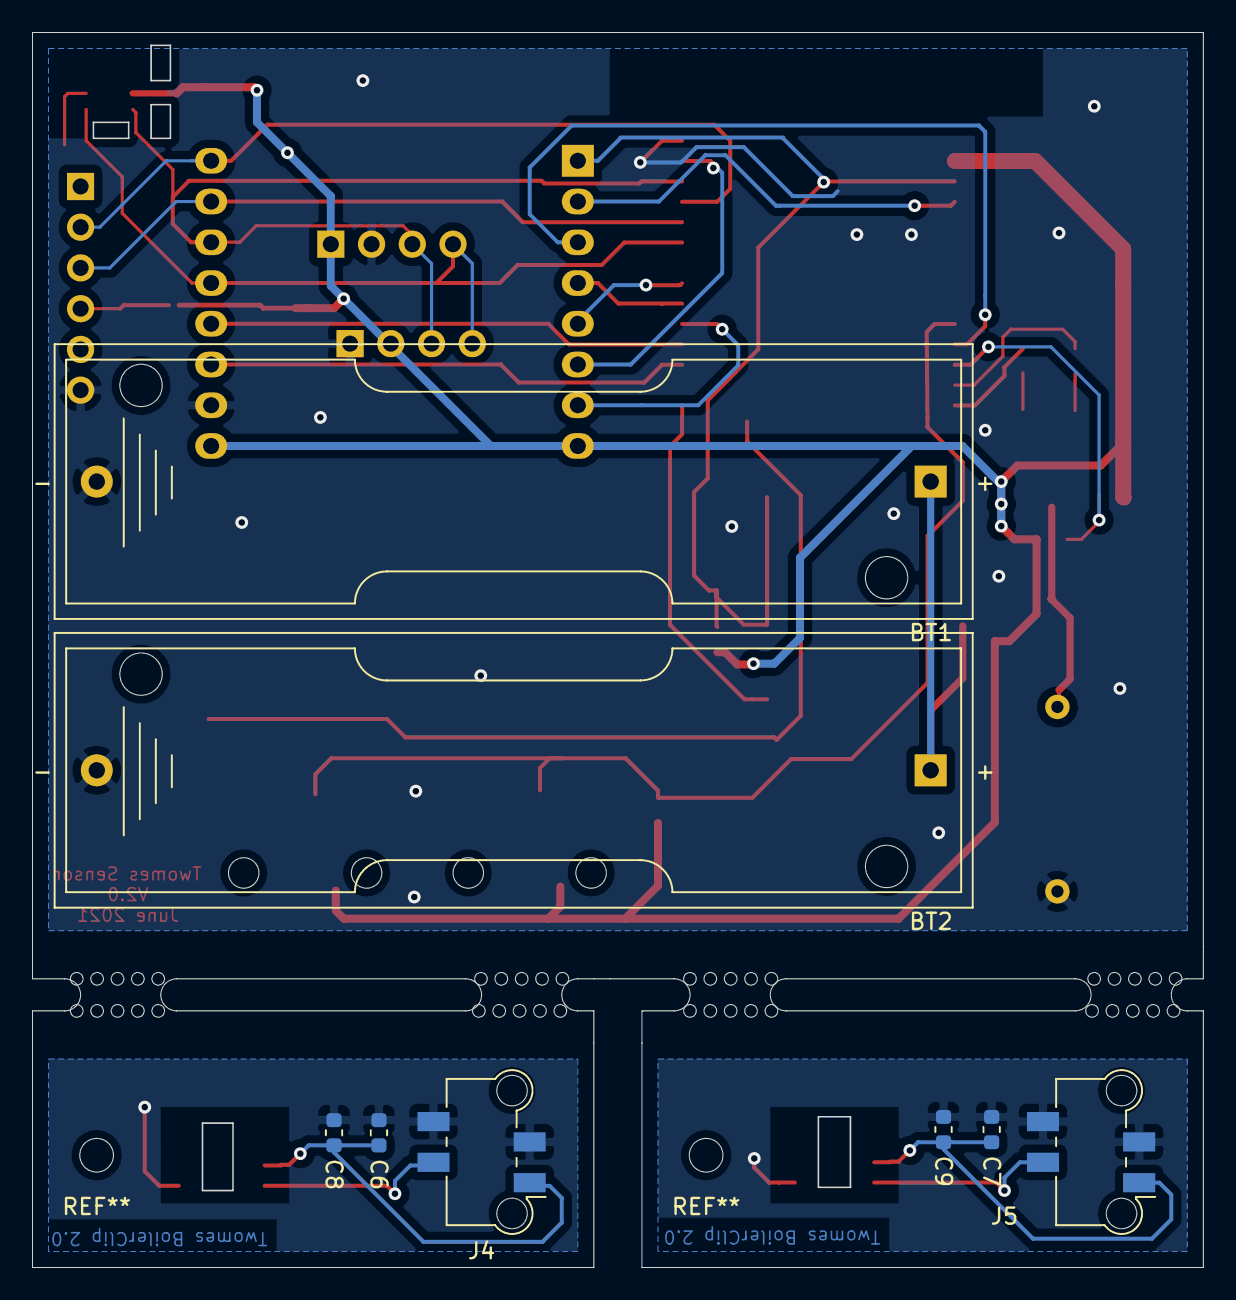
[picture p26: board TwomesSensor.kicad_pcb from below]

Board: 2 copper layers, 73.0 x 77.0 mm, 40 parts (8 on the bottom side), 32 nets.

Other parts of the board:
CO2-Bare, CO2-Breakout: Conn_01x04_Female; PinHeader_1x04_P2.54mm_Vertical

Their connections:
/ESP_SCL: CO2-Bare.3, CO2-Breakout.3; also elsewhere on the board
/ESP_SDA: CO2-Bare.4, CO2-Breakout.4; also elsewhere on the board
GND: CO2-Bare.1, CO2-Breakout.2; also elsewhere on the board
VCC: CO2-Bare.2, CO2-Breakout.1; also elsewhere on the board

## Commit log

2021-06-29 Update CO2 sensor footprint
    [TwomesSensor-B_Cu.gbl, TwomesSensor-B_Mask.gbs, TwomesSensor-B_Paste.gbp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]
2021-11-12 Update to new Directory format/name
    [BoilerCase.f3d, BoilerCase.stl, BoilerClamp.f3d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]
2021-11-12 New enclosures with correct slots and new letter names
    [BoilerCase.f3d, BoilerClamp.stl, BoilerSensorButton.stl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]
2021-12-29 directory restructure
    [BOM_SENSOR_JLC.xlsx, BoilerCase.f3d, BoilerClamp.stl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]
2022-01-06 restructured repo and updated README
    [BOM-TwomesBoilerSensor.csv, BOM-TwomesRoomSensor.csv, BOM_SENSOR_JLC.xlsx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]
2022-01-06 add sources for clamps
    [BoilerClamp.f3d, twomes-boiler-monitor-enclosure-clamp.f3d, twomes-boiler-monitor-enclosure-clamp.step]
2022-01-06 different assembly instructions for room monitor
    [BOM-TwomesRoomSensor.csv]
2022-04-01 Update README.md
    updates ESP32 module that was actually used
